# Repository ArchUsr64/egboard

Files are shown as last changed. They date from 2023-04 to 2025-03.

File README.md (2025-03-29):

# Egboard

A column staggered ortholinear keyboard powered by the Raspberry Pi Pico running Rust!
top_compressed

## Features
- Mouse Input
- Multiple layers
- 1 kHz polling rate
- One-shot modifiers

## Typing Test:
https://github.com/ArchUsr64/egboard/assets/83179501/ff6934fe-465e-4626-92a0-021e62bb25d1

## Bulding the firmware
Pre-built `uf2` is available at [releases](https://github.com/ArchUsr64/egboard/releases)    
Otherwise to build from source:
1. Install [rust](https://rust-lang.org)
2. Download the toolchain for the `thumbv6m-none-eabi`(ARM Cortex-M0+) target 
   `rustup target add thumbv6m-none-eabi`
3. Build the firmware elf  
   `cargo build --release`
4. Converting elf to uf2 using [elf2uf2-rs](https://github.com/JoNil/elf2uf2-rs)  
   `cargo install elf2uf2-rs`  
   `elf2uf2-rs target/thumbv6m-none-eabi/release/egboard egboard.uf2`
5. A new `egboard.uf2` file should be created

### Uploading the uf2 to pico:
1. Enter the pico into bootloader mode by holding the `Bootsel` button
2. Mount the pico's mass storage to the PC's file system (should be done automatically in most Operating Systems)
3. Copy the `firmware.uf2` file to the mounted location

## Hardware

The hardware files required to generate the top and bottom plates can be found [here](https://github.com/ArchUsr64/egboard/tree/main/files/hardware)

### Parts required:
| Part | Quantity | Description |
|  - | - |  -  |
| Raspberry Pi Pico | 1 | Microcontroller that powers the whole thing |
| M3 screw | 40 | Used to mount the top and bottom plates together |
| M2 screw | 4 | Used to mount the raspberry pi pico to the top plate |
| M3 standoff | 20 | Provide spacing between the top and bottom plate to house the electronics |
| Switch | 38 | Key switches mounted to the top plate (both 3-pin and 5-pin work)|
| Keycaps | 38 | Keycaps for the switches |
| Diodes | 38 | Required to achieve n-key rollover |
| USB Cable | 1 | Used to connect the pico to the computer |
| Bump Switch (optional) | 1 | Used to get the board to bootloader mode |

### Matrix Layout:
Connect the switches in a `10x4` matrix with the following layout:  

wiring

**NOTE:** The above picture shows the layout from top side, flip it horizontally when doing the wiring with the board upside down.

### Wiring:
The diodes should be connected in `Column to Row` ordering i.e the `cathode` of the diode (the side with the line) should be facing away from the keys and the `cathode` of the diodes in same row should all be connected.  
The `anode` of the diodes should each connect to one pin of the switch and the other pin should be connected straight with all the pins of switches in same column. 
For wiring the Raspberry Pi Pico, the indexing used in wiring diagram above correspond to the pico's pinout as follows:

| Row | 0 | 1 | 2 | 3 |
|  -  | - | - | - | - |
| Pin | 0 | 1 | 2 | 3 |

| Column | 0 | 1 | 2 | 3 | 4 | 5 | 6 | 7 | 8 | 9 |
| - | - | - | - | - | - | - | - | - | - | - |
| Pin | 13 | 12 | 11 | 10 | 9 | 8 | 7 | 6 | 5 | 4 | 

## Keymap configuration
The keymap for the board is specified in [`default_keymap.rs`](https://github.com/ArchUsr64/egboard/blob/main/src/default_keymap.rs) file.  
Each `Keymap` can include upto 256 `Layers` which are added using the `add_layer` method.  
Each `Layer` comprises of a 30 element array for the finger cluster and 8 element array for the thumb clusters.  

### Provided default keymap
#### Layer 0

#### Layer 1

#### Layer 2

#### Layer 3


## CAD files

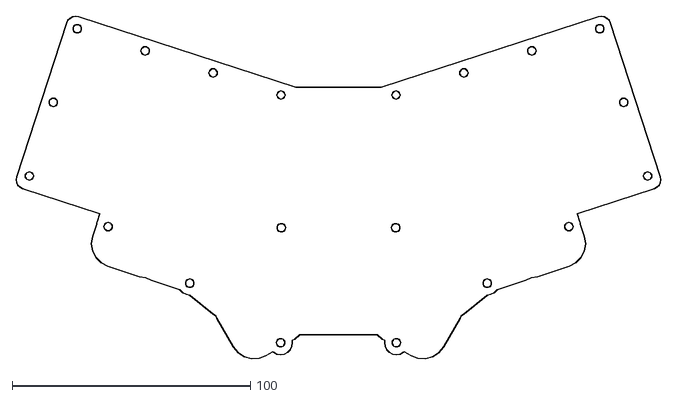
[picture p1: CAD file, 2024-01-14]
files/hardware/bottom.dxf
270.8 x 143.8

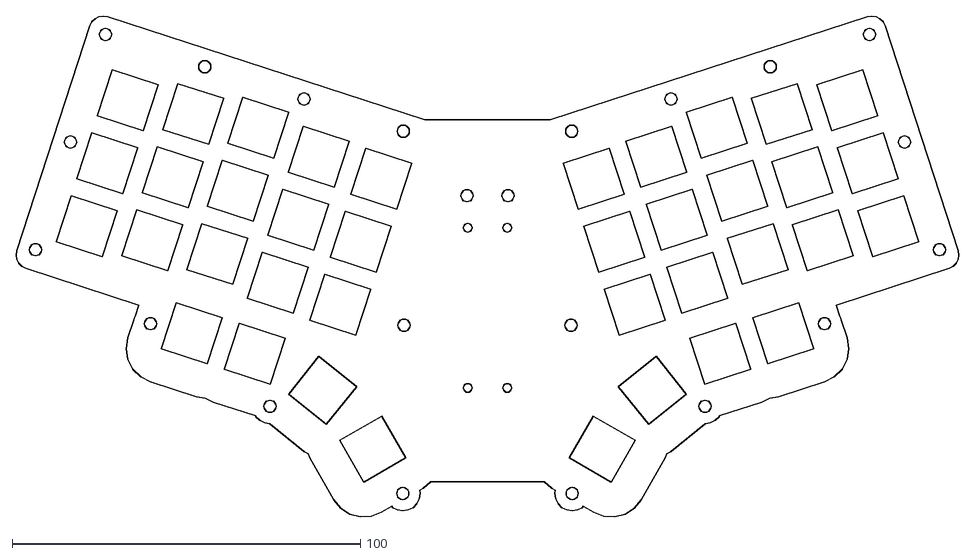
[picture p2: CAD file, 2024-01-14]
files/hardware/top.dxf
270.8 x 143.8

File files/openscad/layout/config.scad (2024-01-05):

offset = 10;

//Key dimensions
key_gap = 5.15;
key_hole_size = 13.9;
key_size = key_gap + key_hole_size;

//Finger cluster layout
key_column_count = [3, 3, 3, 3, 3];
key_y_offset = [-4, -2, 0, -2.5, -3];

//Thumb cluster config
thumb_axis2 = [57.15, -123];
thumb_r = 61;
linear_univ_offset = [0, 0];
key_rotation_init = 48.066;
rotating_key_count = 3;
linear_key_count = 1;

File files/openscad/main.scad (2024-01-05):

// clang-format off
use<layout/layout.scad>;
// clang-format on
$fn = 20;
screw_hole_m3 = 3.5;
screw_hole_m2 = 2.5;
screw_offset = 10;

module layout_with_holes(holes = false) {
	angle = -18;
	offset = 20;
	module holes(size) {
		holes = [
			[5, -5],
			[35, -5],
			[65, -5],
			[95, -5],
			[5, -37.5],
			[5, -70],
			[43, -80],
			[83, -92],
			[127, -104],
		];
		for (i = [0:len(holes) - 1]) {
			translate([holes[i][0], holes[i][1], 0]) circle(d = size);
		}
	}
	module plate() {
		difference() {
			union() {
				translate([108, -50, 0]) rotate(16) square([22, 85], center = true);
				layout(false);
				rounded = 4;
				size = [106.1 - 2 * rounded, 76 - 2 * rounded];
				offset(rounded) translate([rounded, -size[1] - rounded, 0]) square(size);
				holes(screw_offset);
			}
			holes(screw_hole_m3);
			if (holes) {
				layout(true);
			}
		}
	}
	size = [40, 104];
	translate([0, size[1] / 2 - 10, 0]) square(size, center = true);
	mirror([1, 0, 0]) translate([-offset, 0, 0]) rotate(angle) translate([-127, 90, 0])
		plate();
	translate([-offset, 0, 0]) rotate(angle) translate([-127, 90, 0])
		plate();
}
bottom();
// rotate(90) translate([0, -50, 0]) top();
offset = 10;
channel_height = 103;
module top() {
	module type_a_screw_holes() {
		x_offset = 11.82;
		y_offset = -2.755;
		translate([x_offset / 2, y_offset, 0]) circle(d = screw_hole_m3);
		translate([-x_offset / 2, y_offset, 0]) circle(d = screw_hole_m3);
	}
	module pi_pico() {
		hole_offset_x = 11.4;
		hole_offset_y = 46;
		holes =
			[[hole_offset_x / 2, hole_offset_y / 2],
			 [hole_offset_x / 2, -hole_offset_y / 2],
			 [-hole_offset_x / 2, hole_offset_y / 2],
			 [-hole_offset_x / 2, -hole_offset_y / 2]];
		for (i = [0:len(holes) - 1]) {
			translate([holes[i][0], holes[i][1], 0]) circle(d = screw_hole_m2);
		}
	}
	difference() {
		union(){
			layout_with_holes(holes = true);
			holes(screw_offset);
		}
		translate([0, 40, 0]) pi_pico();
		translate([0, 75, 0])type_a_screw_holes();
		holes(screw_hole_m3);
	}
}

module bottom() {
	difference() {
		union(){
			layout_with_holes(holes = false);
			holes(screw_offset);
		}
		holes(screw_hole_m3);
	}
}

module holes(size) {
	holes = [
		[24, 35],
	];
	for (i = [0:len(holes) - 1]) {
		translate([holes[i][0], holes[i][1], 0]) circle(d = size);
		translate([-holes[i][0], holes[i][1], 0]) circle(d = size);
	}
}

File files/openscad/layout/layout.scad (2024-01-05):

include<config.scad>;
module layout(holes = true) {
	diff = key_hole_size / 2 + offset;
	translate([diff, -diff, 0]) {
		if (holes) {
			holes();
		} else {
			offset(offset) holes(true);
		}
	}
}
layout(holes = true);
color([0, 1, 0, 0.2]) layout(false);
module holes(holes = false) {
	module square_centered(center2 = [0, 0]) {
		size = key_hole_size;
		if (holes) {
			size = key_size;
		}
		translate([center2[0], center2[1], 0])
		square([size, size], center = true);
	}

	for (i = [0:len(key_column_count) - 1]) {
		center_x = i * key_size;
		for (j = [0:key_column_count[i] - 1]) {
			center_y = j * -key_size + key_y_offset[i];
			square_centered([center_x, center_y]);
		}
	}

	function rotation_offset_till(radius, key_size, i) =
		i * 2 * atan(.5 * key_size / (radius - key_size * 0.5));
	for (i = [0:rotating_key_count - 1]) {
		rotation_offset = rotation_offset_till(thumb_r, key_size, i) + key_rotation_init;
		translate([
			thumb_axis2[0] + thumb_r * cos(rotation_offset),
			thumb_axis2[1] + thumb_r * sin(rotation_offset),
			0
		]) rotate(rotation_offset) square_centered();
	}
	linear_key_pos_init2 = [
		thumb_axis2[0]
			+ thumb_r
				* cos(
					key_rotation_init
					+ rotation_offset_till(thumb_r, key_size, rotating_key_count - 1)),
		thumb_axis2[1]
			+ thumb_r
				* sin(
					key_rotation_init
					+ rotation_offset_till(thumb_r, key_size, rotating_key_count - 1)),
	] + linear_univ_offset;
	linear_offset_sum = (key_size * linear_key_count);
	if (linear_key_count > 0)
		for (i = [0:linear_key_count - 1]) {
			index_actual = linear_key_count - i - 1;
			linear_offset = linear_offset_sum - key_size * index_actual;
			square_centered(
				[linear_key_pos_init2[0] - linear_offset, linear_key_pos_init2[1]]);
		}
}

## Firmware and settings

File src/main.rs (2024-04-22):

#![no_std]
#![no_main]

pub const USB_POLLING_DELAY_MS: u32 = 1;
pub const DEBOUNCE_BUFFER_SIZE: usize = 64;

mod keymap;
mod keys_macro;
mod panic_handler;
use core::panic;
use keymap::Keymap;

use defmt_rtt as _;
use rp_pico::{entry, hal};

use embedded_hal::digital::v2::*;
use embedded_hal::prelude::*;
use fugit::ExtU32;
use heapless::Vec;
use usb_device::class_prelude::*;
use usb_device::prelude::*;
use usbd_human_interface_device::device::mouse::WheelMouseReport;
use usbd_human_interface_device::prelude::*;

#[entry]
fn main() -> ! {
	use cortex_m::delay::Delay;
	use rp_pico::hal::{
		pac::{CorePeripherals, Peripherals},
		Clock, Watchdog,
	};
	let mut pac = Peripherals::take().unwrap();
	let core = CorePeripherals::take().unwrap();
	let mut watchdog = Watchdog::new(pac.WATCHDOG);
	let clocks = rp_pico::hal::clocks::init_clocks_and_plls(
		rp_pico::XOSC_CRYSTAL_FREQ,
		pac.XOSC,
		pac.CLOCKS,
		pac.PLL_SYS,
		pac.PLL_USB,
		&mut pac.RESETS,
		&mut watchdog,
	)
	.ok()
	.unwrap();
	let timer = hal::Timer::new(pac.TIMER, &mut pac.RESETS);
	let mut delay = Delay::new(core.SYST, clocks.system_clock.freq().to_Hz());
	let sio = hal::Sio::new(pac.SIO);
	let pins = rp_pico::Pins::new(
		pac.IO_BANK0,
		pac.PADS_BANK0,
		sio.gpio_bank0,
		&mut pac.RESETS,
	);
	let usb_bus = UsbBusAllocator::new(hal::usb::UsbBus::new(
		pac.USBCTRL_REGS,
		pac.USBCTRL_DPRAM,
		clocks.usb_clock,
		true,
		&mut pac.RESETS,
	));

	use usbd_human_interface_device::device;
	let mut egboard = UsbHidClassBuilder::new()
		.add_interface(device::keyboard::NKROBootKeyboardConfig::default())
		.add_interface(device::mouse::WheelMouseConfig::default())
		.build(&usb_bus);

	let mut usb_dev = UsbDeviceBuilder::new(&usb_bus, UsbVidPid(0x6969, 0x1234))
		.manufacturer("ArchUsr64")
		.product("Rusty Egboard")
		.build();

	let mut led = pins.led.into_push_pull_output();
	led.set_high().unwrap();

	use core::convert::Infallible;
	use embedded_hal::digital::v2::{InputPin, OutputPin};

	let mut col: [&mut dyn OutputPin<Error = Infallible>; 10] =
		output_keys!(pins, 13, 12, 11, 10, 9, 8, 7, 6, 5, 4);
	col.iter_mut().for_each(|pin| pin.set_low().unwrap());
	let row: [&dyn InputPin<Error = Infallible>; 4] = input_keys!(pins, 0, 1, 2, 3);

	let mut usb_polling_count_down = timer.count_down();
	usb_polling_count_down.start(USB_POLLING_DELAY_MS.millis());

	let mut tick_count_down = timer.count_down();
	tick_count_down.start(1.millis());

	let mut state_buffer = Vec::<_, DEBOUNCE_BUFFER_SIZE>::new();
	(0..DEBOUNCE_BUFFER_SIZE).for_each(|_| {
		let _ = state_buffer.push(0);
	});
	let mut prev_mouse_button = 0;

	let keymap = Keymap::default();
	let empty_mouse_report = WheelMouseReport::default();

	loop {
		state_buffer.remove(0);
		let mut state = 0;
		for (i, col_pin) in col.iter_mut().enumerate() {
			for (j, row_pin) in row.iter().enumerate() {
				let _ = col_pin.set_high();
				delay.delay_us(1);
				if row_pin.is_high().unwrap() {
					state |= 1 << ((j * 10 + i) as u64);
				}
				let _ = col_pin.set_low();
			}
		}
		let _ = state_buffer.push(state);

		if usb_polling_count_down.wait().is_ok() {
			let debounced_state = state_buffer.iter().fold(!0, |acc, x| acc & x);
			let (key_events, mouse_report) =
				keymap.generate_events(keymap::key_state(debounced_state));

			match egboard
				.interface::<device::keyboard::NKROBootKeyboardInterface<'_, _>, _>()
				.write_report(key_events)
			{
				Err(UsbHidError::WouldBlock) => {}
				Err(UsbHidError::Duplicate) => {}
				Ok(_) => {}
				Err(e) => {
					panic!("Failed to write keyboard report: {:?}", e)
				}
			};

			if mouse_report != empty_mouse_report || mouse_report.buttons != prev_mouse_button {
				match egboard
					.interface::<device::mouse::WheelMouseInterface<'_, _>, _>()
					.write_report(&mouse_report)
				{
					Err(UsbHidError::WouldBlock) => {}
					Ok(_) => {
						prev_mouse_button = mouse_report.buttons;
					}
					Err(e) => {
						core::panic!("Failed to write mouse report: {:?}", e)
					}
				};
			}
		}

		//Tick once per ms
		if tick_count_down.wait().is_ok() {
			match egboard
				.interface::<device::keyboard::NKROBootKeyboardInterface<'_, _>, _>()
				.tick()
			{
				Err(UsbHidError::WouldBlock) => {}
				Ok(_) => {}
				Err(e) => {
					panic!("Failed to process keyboard tick: {:?}", e)
				}
			};
		}

		if usb_dev.poll(&mut [&mut egboard]) {
			match egboard
				.interface::<device::keyboard::NKROBootKeyboardInterface<'_, _>, _>()
				.read_report()
			{
				Err(UsbError::WouldBlock) => {
					//do nothing
				}
				Err(e) => {
					panic!("Failed to read keyboard report: {:?}", e)
				}
				Ok(leds) => {
					led.set_state(PinState::from(leds.caps_lock)).ok();
				}
			}
		}
	}
}

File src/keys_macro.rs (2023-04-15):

#[macro_export]
macro_rules! output_keys {
	(@num $pin:expr, 0) => {$pin.gpio0.into_push_pull_output()};
	(@num $pin:expr, 1) => {$pin.gpio1.into_push_pull_output()};
	(@num $pin:expr, 2) => {$pin.gpio2.into_push_pull_output()};
	(@num $pin:expr, 3) => {$pin.gpio3.into_push_pull_output()};
	(@num $pin:expr, 4) => {$pin.gpio4.into_push_pull_output()};
	(@num $pin:expr, 5) => {$pin.gpio5.into_push_pull_output()};
	(@num $pin:expr, 6) => {$pin.gpio6.into_push_pull_output()};
	(@num $pin:expr, 7) => {$pin.gpio7.into_push_pull_output()};
	(@num $pin:expr, 8) => {$pin.gpio8.into_push_pull_output()};
	(@num $pin:expr, 9) => {$pin.gpio9.into_push_pull_output()};
	(@num $pin:expr, 10) => {$pin.gpio10.into_push_pull_output()};
	(@num $pin:expr, 11) => {$pin.gpio11.into_push_pull_output()};
	(@num $pin:expr, 12) => {$pin.gpio12.into_push_pull_output()};
	(@num $pin:expr, 13) => {$pin.gpio13.into_push_pull_output()};
	(@num $pin:expr, 14) => {$pin.gpio14.into_push_pull_output()};
	(@num $pin:expr, 15) => {$pin.gpio15.into_push_pull_output()};
	(@num $pin:expr, 16) => {$pin.gpio16.into_push_pull_output()};
	(@num $pin:expr, 17) => {$pin.gpio17.into_push_pull_output()};
	(@num $pin:expr, 18) => {$pin.gpio18.into_push_pull_output()};
	(@num $pin:expr, 19) => {$pin.gpio19.into_push_pull_output()};
	(@num $pin:expr, 20) => {$pin.gpio20.into_push_pull_output()};
	(@num $pin:expr, 21) => {$pin.gpio21.into_push_pull_output()};
	(@num $pin:expr, 22) => {$pin.gpio22.into_push_pull_output()};
	(@num $pin:expr, 23) => {$pin.gpio23.into_push_pull_output()};
	(@num $pin:expr, 24) => {$pin.gpio24.into_push_pull_output()};
	(@num $pin:expr, 25) => {$pin.gpio25.into_push_pull_output()};
	(@num $pin:expr, 26) => {$pin.gpio26.into_push_pull_output()};
	(@num $pin:expr, 27) => {$pin.gpio27.into_push_pull_output()};
	(@num $pin:expr, 28) => {$pin.gpio28.into_push_pull_output()};
	($pin:expr, $($N:tt), +) => {
		[$(&mut output_keys!(@num $pin, $N)), *]
	}
}
#[macro_export]
macro_rules! input_keys {
	(@num $pin:expr, 0) => {$pin.gpio0.into_pull_down_input()};
	(@num $pin:expr, 1) => {$pin.gpio1.into_pull_down_input()};
	(@num $pin:expr, 2) => {$pin.gpio2.into_pull_down_input()};
	(@num $pin:expr, 3) => {$pin.gpio3.into_pull_down_input()};
	(@num $pin:expr, 4) => {$pin.gpio4.into_pull_down_input()};
	(@num $pin:expr, 5) => {$pin.gpio5.into_pull_down_input()};
	(@num $pin:expr, 6) => {$pin.gpio6.into_pull_down_input()};
	(@num $pin:expr, 7) => {$pin.gpio7.into_pull_down_input()};
	(@num $pin:expr, 8) => {$pin.gpio8.into_pull_down_input()};
	(@num $pin:expr, 9) => {$pin.gpio9.into_pull_down_input()};
	(@num $pin:expr, 10) => {$pin.gpio10.into_pull_down_input()};
	(@num $pin:expr, 11) => {$pin.gpio11.into_pull_down_input()};
	(@num $pin:expr, 12) => {$pin.gpio12.into_pull_down_input()};
	(@num $pin:expr, 13) => {$pin.gpio13.into_pull_down_input()};
	(@num $pin:expr, 14) => {$pin.gpio14.into_pull_down_input()};
	(@num $pin:expr, 15) => {$pin.gpio15.into_pull_down_input()};
	(@num $pin:expr, 16) => {$pin.gpio16.into_pull_down_input()};
	(@num $pin:expr, 17) => {$pin.gpio17.into_pull_down_input()};
	(@num $pin:expr, 18) => {$pin.gpio18.into_pull_down_input()};
	(@num $pin:expr, 19) => {$pin.gpio19.into_pull_down_input()};
	(@num $pin:expr, 20) => {$pin.gpio20.into_pull_down_input()};
	(@num $pin:expr, 21) => {$pin.gpio21.into_pull_down_input()};
	(@num $pin:expr, 22) => {$pin.gpio22.into_pull_down_input()};
	(@num $pin:expr, 23) => {$pin.gpio23.into_pull_down_input()};
	(@num $pin:expr, 24) => {$pin.gpio24.into_pull_down_input()};
	(@num $pin:expr, 25) => {$pin.gpio25.into_pull_down_input()};
	(@num $pin:expr, 26) => {$pin.gpio26.into_pull_down_input()};
	(@num $pin:expr, 27) => {$pin.gpio27.into_pull_down_input()};
	(@num $pin:expr, 28) => {$pin.gpio28.into_pull_down_input()};
	($pin:expr, $($N:tt), +) => {
		[$(&input_keys!(@num $pin, $N)), *]
	}
}

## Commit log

2022-10-03 Added scad and model files
    [base_plate.scad, bottom_plate.dxf, bottom_plate.scad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]
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2022-11-08 Keycaps more rounded now
    [key_caps.scad, keycaps.stl]
2022-11-09 Even more rounded keycaps
    [key_caps.scad, keycaps.scad, keycaps.stl]
2023-02-02 Removed pre-existing files
    [base_plate.scad, bottom_plate.dxf, bottom_plate.scad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]
2023-02-02 Added rust logo
    [logo.scad]
2023-02-03 implemented top plate key layout
    [config.scad, layout.scad]
2023-02-03 implemented right and left top plates
    [config.scad, top_plate.scad]
2023-02-03 fixed screw size for switch
    [top_plate.scad]
2023-02-03 updated battery size
    [top_plate.scad]
2023-02-03 reduced rust logo size
    [top_plate.scad]
2023-02-03 modularised top_plate models
    [top_plate.scad]
2023-02-03 removed unnecessary echo
    [layout.scad]
2023-02-05 implemented global config for battery position
    [config.scad, top_plate.scad]
2023-02-05 Added screw holes for right top plate
    [config.scad, top_plate.scad]
2023-02-05 Added screw holes for left top plate
    [config.scad, top_plate.scad]
2023-02-05 Made magnet dimensions more configurable
    [config.scad, top_plate.scad]
2023-02-05 changed battery hole size for top plate
    [top_plate.scad]
2023-02-05 implemented upper middle layers
    [config.scad, middle_upper.scad]
2023-02-06 Removed unnecessary holes property from middle upper plates
    [middle_upper.scad]
2023-02-10 implemented basic sliding channel generator
    [config.scad]
2023-02-10 implemented slider
    [config.scad, slider.scad]
2023-02-10 added main module rendering for each
    [middle_lower.scad, middle_upper.scad, top_plate.scad]
2023-02-10 updated some values
    [config.scad, middle_upper.scad]
2023-02-10 implemented lower middle layer
    [middle_lower.scad]
2023-02-14 implemented slider cover
    [config.scad, slider_cover.scad]
2023-02-16 implemented magnet holes for the slider
    [slider_cover.scad]
2023-02-16 implemented magnet holes for slider cover part 2
    [config.scad]
2023-02-16 adjusted slider channel wall thickness
    [config.scad]
2023-02-16 added screw holes for sliding channel
    [config.scad, middle_lower.scad, slider_cover.scad]
2023-02-16 implemented bottom plates
    [bottom.scad]
2023-02-16 some refactoring some commenting
    [bottom.scad, config.scad, middle_lower.scad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]
2023-02-16 implemented battery zip tie holes
    [bottom.scad, config.scad]
2023-02-16 made standoff holes parallel to slider holes
    [config.scad]
2023-02-16 added support for standoff holes
    [middle_lower.scad, middle_upper.scad]
2023-02-16 implemented hole for the hooker
    [bottom.scad, hooker.scad]
2023-02-17 changed sliding channel length
    [config.scad, hooker.scad]
2023-02-17 added holes for pi pico
    [bottom.scad, config.scad]
2023-02-17 made battery position consistent with sliding channel
    [bottom.scad, config.scad]
2023-02-17 added holes for PCB on right bottom
    [bottom.scad, config.scad]
2023-02-17 removed battery hole from right top platee
    [top_plate.scad]
2023-02-17 implemented holes for type c on left half
    [bottom.scad, config.scad, middle_lower.scad]
2023-02-17 implemented holes for type a on both
    [bottom.scad, config.scad, middle_lower.scad]
2023-02-17 implemented holes for barrel jack on right half
    [bottom.scad, config.scad, middle_lower.scad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]
2023-02-17 added holes only model for logo
    [logo.scad]
2023-02-17 implemented bottom screen for rust logo
    [config.scad, logo_screen.scad, top_plate.scad]
2023-02-19 tweaked around some values
    [config.scad, hooker.scad, middle_upper.scad]
2023-02-19 split each middle layer in two
    [config.scad, middle_lower.scad, middle_upper.scad]
2023-02-19 added support for sliding channel slots
    [middle_lower.scad]
2023-02-20 tweaked logo dimensions
    [config.scad, logo_screen.scad, top_plate.scad]
2023-02-22 implemented holes for sliding channel
    [bottom.scad, config.scad, hooker.scad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]
2023-02-22 likely the final commit for hardware
    [bottom.scad, config.scad, hooker.scad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]
2023-03-01 simplified rust logo geometry
    [logo.scad, logo_screen.scad, rust_logo.stl]
2023-03-07 Added final hardware files
    [generator.scad, mm_1.dxf, mm_10.dxf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]
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2023-04-03 removed unnecessary files
    [bottom.scad, config.scad, generator.scad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]
2023-04-04 added top and bottom plate modules
    [config.scad, layout.scad, logo.scad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]
2023-04-14 added hardware files
    [bottom.dxf, our_screen.dxf, rust_screen.dxf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]
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2023-04-24 code refactor
    [layout.scad]
2023-04-24 changed layout holes property to `only_holes`
    [layout.scad]
2023-04-24 removed rust logo
    [logo.scad, main.scad, rust_logo.stl]
2023-04-24 changed layout configuration
    [config.scad]
2023-04-24 removed oled module
    [main.scad]
2023-04-24 added tilted base_plate
    [config.scad, main.scad]
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2023-04-27 added new hardware files
    [bottom.dxf, main.scad, top.dxf]
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2024-01-05 updated hardware to v2
    [config.scad, layout.scad, main.scad]
2024-01-14 updated hardware files to v2
    [bottom.dxf, top.dxf]
